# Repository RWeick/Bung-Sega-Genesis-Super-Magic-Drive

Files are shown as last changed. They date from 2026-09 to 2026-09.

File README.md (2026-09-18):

# Bung-Sega-Genesis-Super-Magic-Drive
The bioses and Kicad files for the Bung Super Magic Drive for the Sega Genesis

PCB Thicknesses are documented in the Kicad files.

The motherboard contains two modifications from the original: a bodged resistor pack now has its own footprint and there is a solder jumper to switch between original 16M RAM mode and 32M RAM mode. The 32M RAM mode was a modification that would be done when you sent your system back to Bung for the upgrade. Unfortunately it appears that the upgrade also required the CPLD to be upgraded as well, and a modified CPLD has not yet surfaced to be studied. The upgrade solder jumper and 32M RAM board are therefore provided for a future point where the CPLD is found, studied, and reverse engineered. You may use a 32M RAM card with this system, but it will only register 16M of RAM.

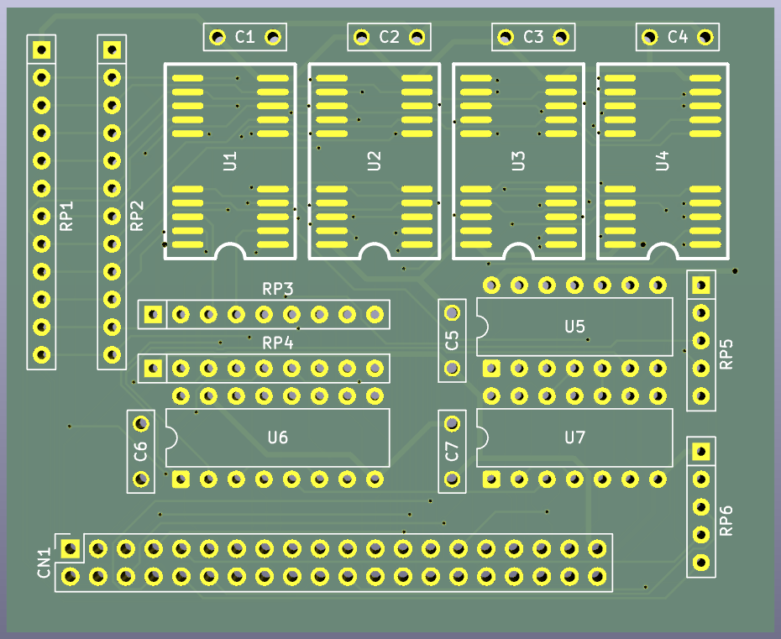
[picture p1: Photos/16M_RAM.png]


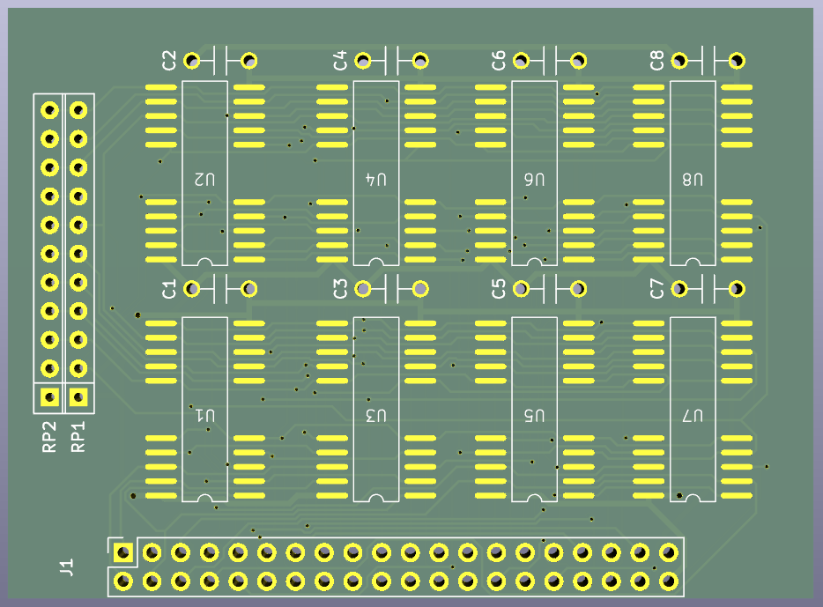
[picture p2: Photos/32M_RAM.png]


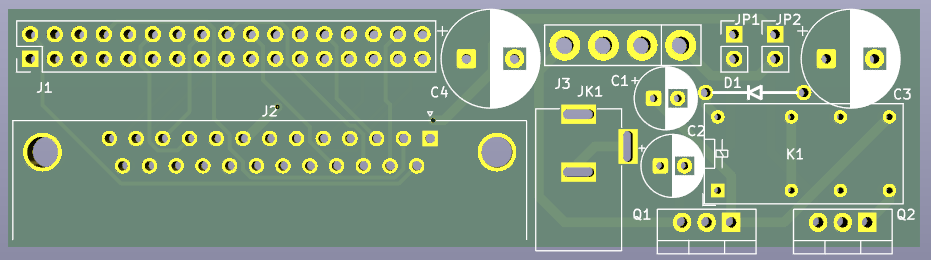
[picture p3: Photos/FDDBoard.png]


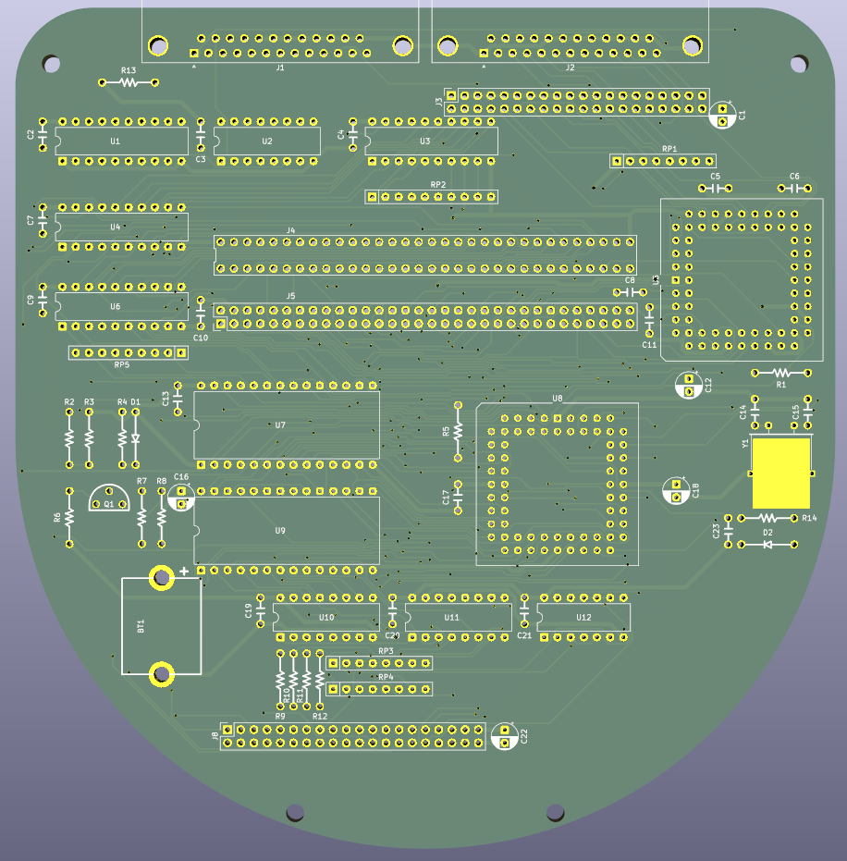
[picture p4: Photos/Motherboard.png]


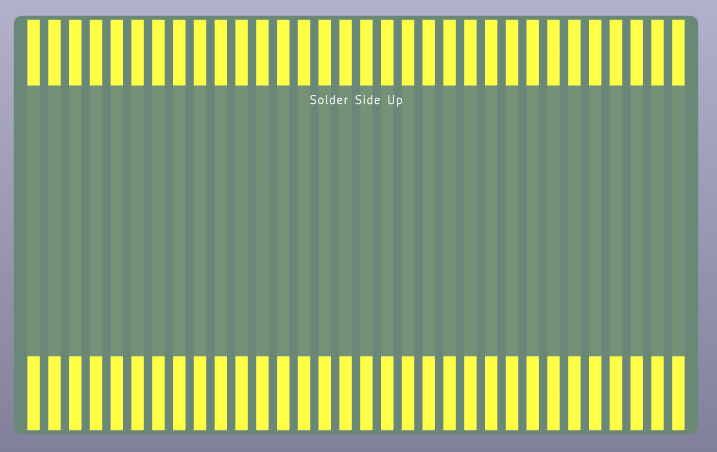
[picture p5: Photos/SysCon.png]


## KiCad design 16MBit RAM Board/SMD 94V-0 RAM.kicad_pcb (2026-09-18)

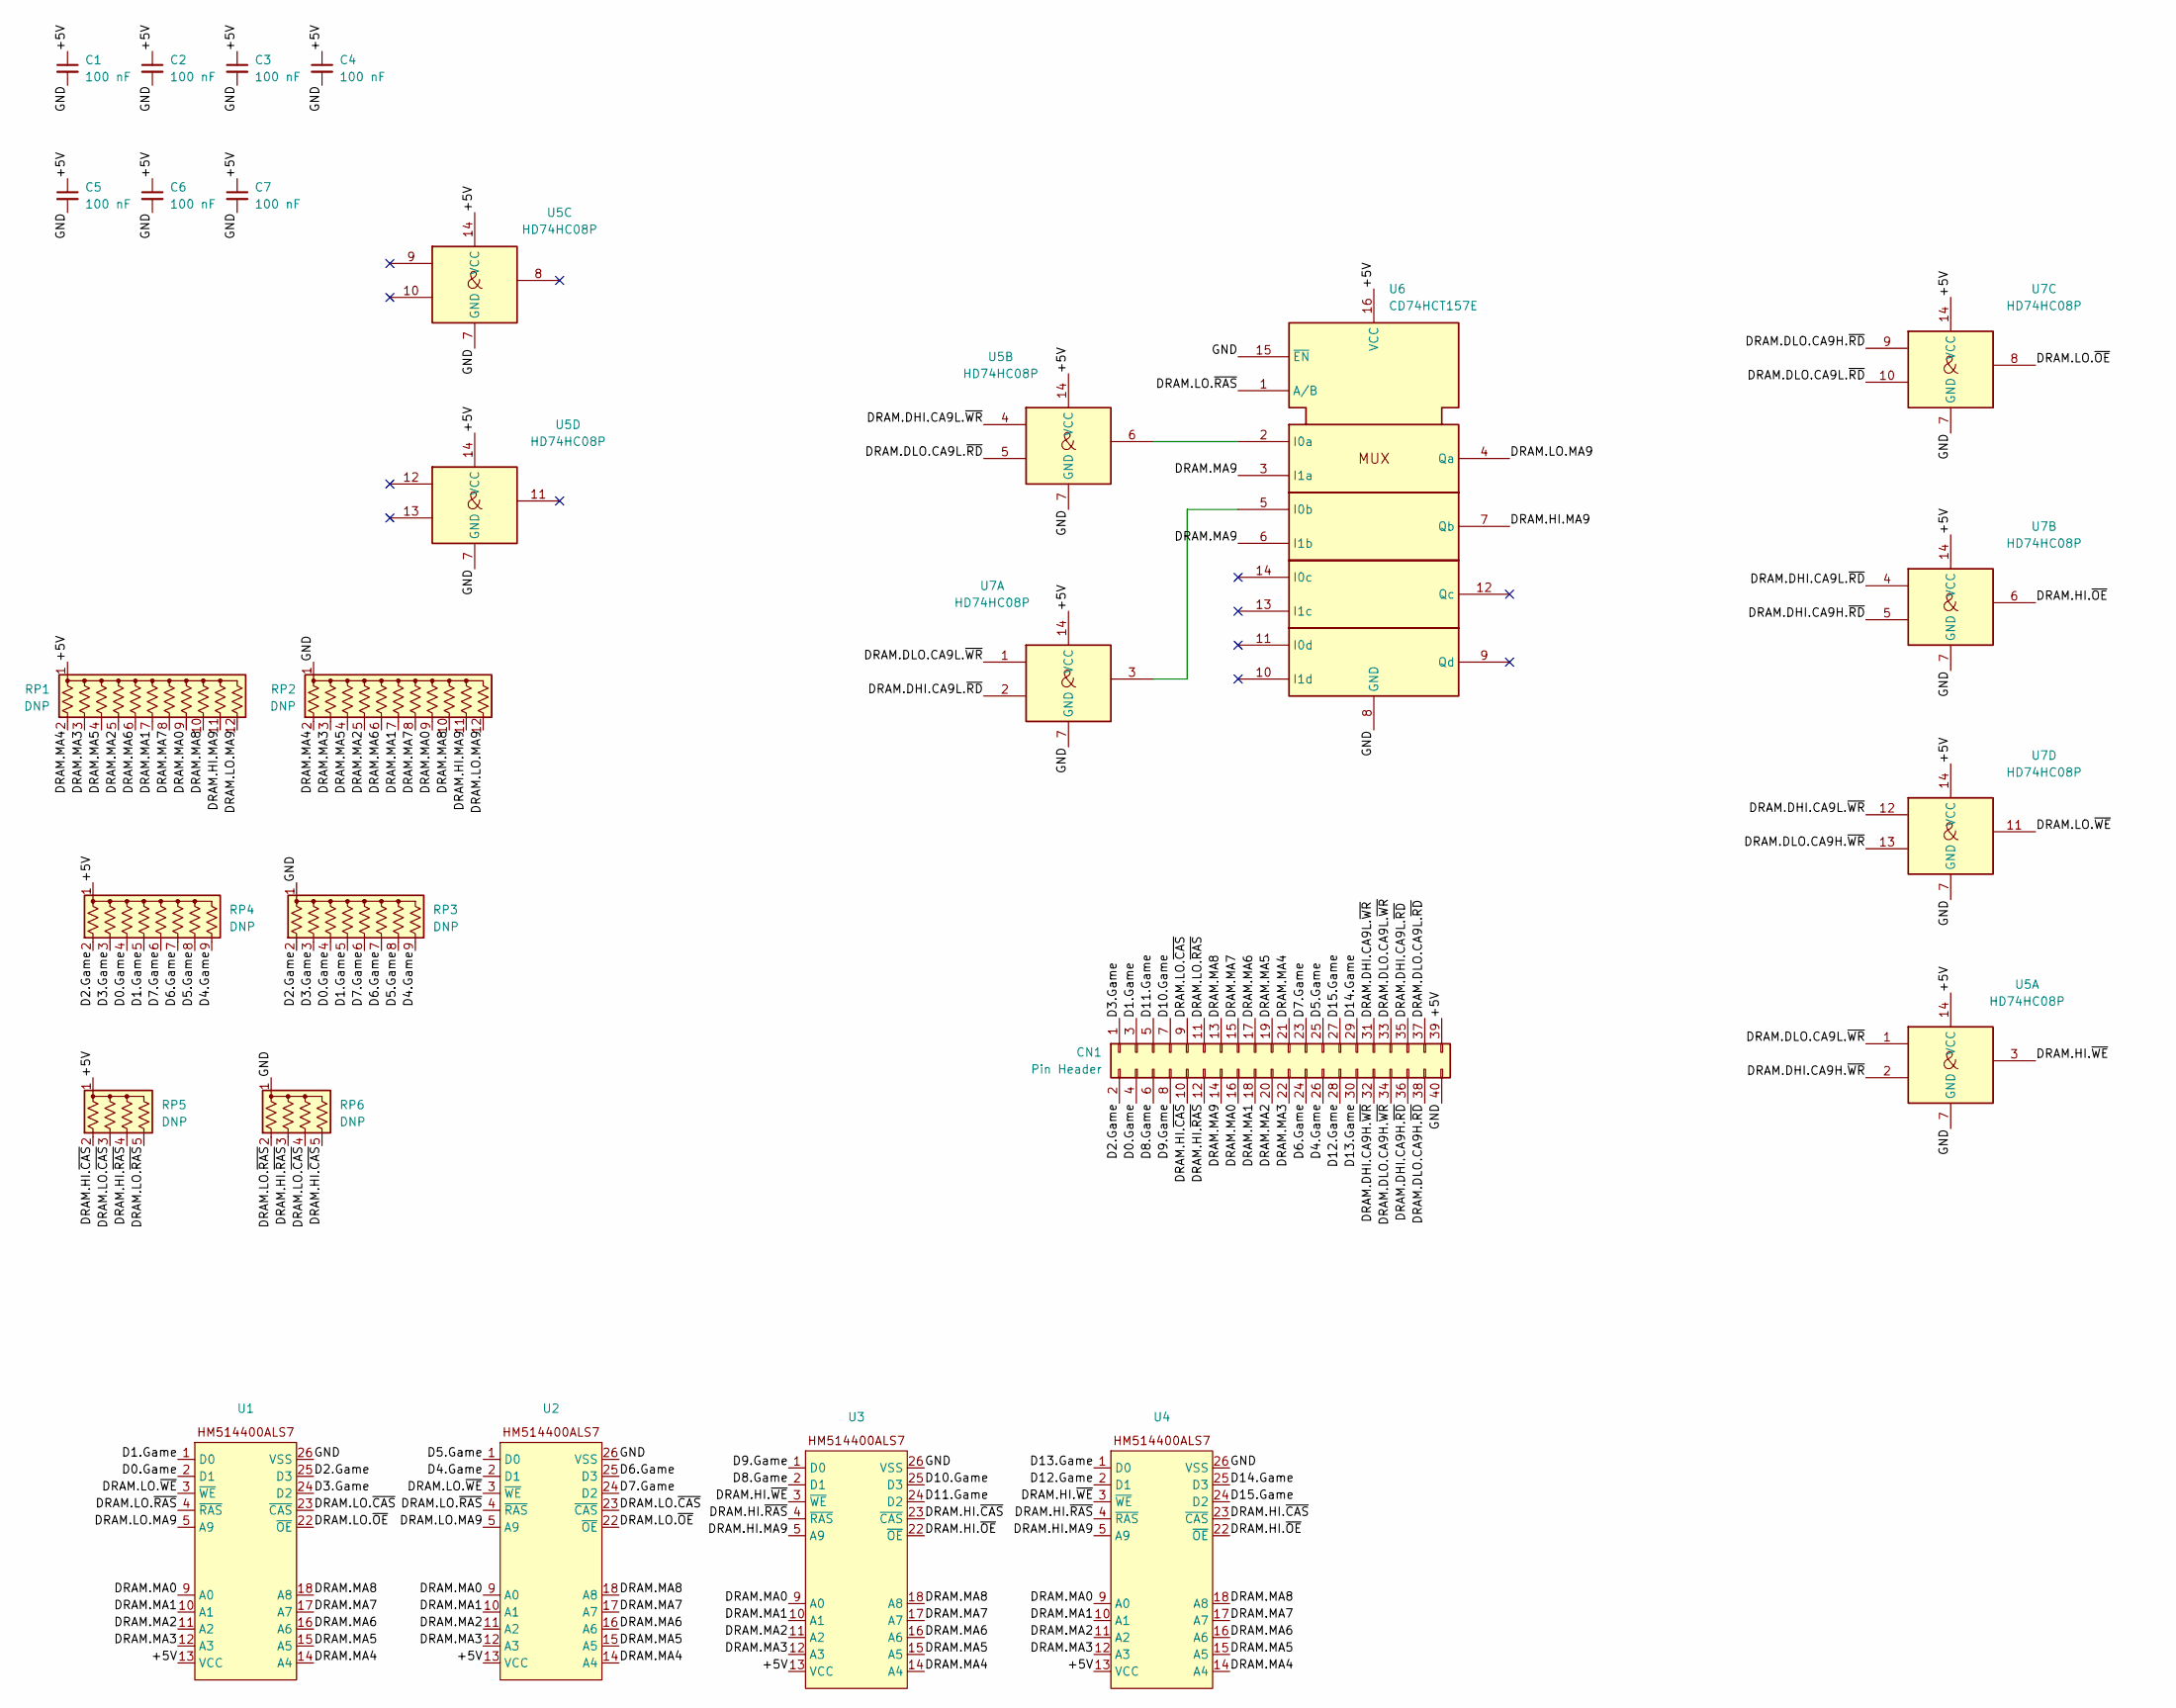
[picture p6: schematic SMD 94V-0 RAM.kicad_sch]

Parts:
C1, C2, C3, C4, C5, C6, C7: 100 nF
CN1: Pin Header
RP1, RP2: DNP; R_Array_SIP12
RP3, RP4: DNP; R_Array_SIP9
RP5, RP6: DNP; R_Array_SIP5
U1, U2, U3, U4: (no value)
U5, U7: HD74HC08P
U6: CD74HCT157E

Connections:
/+5V: C1.1, C2.1, C3.1, C4.1, C5.1, C6.1, C7.1, CN1.39, RP1.1 (common), RP4.1 (common), RP5.1 (common), U1.13 (VCC), U2.13 (VCC), U3.13 (VCC), U4.13 (VCC), U5.14 (VCC), U6.16 (VCC), U7.14 (VCC)
/A0: CN1.16, RP1.9 (R8), RP2.9 (R8), U1.9 (A0), U2.9 (A0), U3.9 (A0), U4.9 (A0)
/A1: CN1.18, RP1.7 (R6), RP2.7 (R6), U1.10 (A1), U2.10 (A1), U3.10 (A1), U4.10 (A1)
/A2: CN1.20, RP1.5 (R4), RP2.5 (R4), U1.11 (A2), U2.11 (A2), U3.11 (A2), U4.11 (A2)
/A3: CN1.22, RP1.3 (R2), RP2.3 (R2), U1.12 (A3), U2.12 (A3), U3.12 (A3), U4.12 (A3)
/A4: CN1.21, RP1.2 (R1), RP2.2 (R1), U1.14 (A4), U2.14 (A4), U3.14 (A4), U4.14 (A4)
/A5: CN1.19, RP1.4 (R3), RP2.4 (R3), U1.15 (A5), U2.15 (A5), U3.15 (A5), U4.15 (A5)
/A6: CN1.17, RP1.6 (R5), RP2.6 (R5), U1.16 (A6), U2.16 (A6), U3.16 (A6), U4.16 (A6)
/A7: CN1.15, RP1.8 (R7), RP2.8 (R7), U1.17 (A7), U2.17 (A7), U3.17 (A7), U4.17 (A7)
/A8: CN1.13, RP1.10 (R9), RP2.10 (R9), U1.18 (A8), U2.18 (A8), U3.18 (A8), U4.18 (A8)
/A9: CN1.14, U6.3 (I1a), U6.6 (I1b)
/GND: C1.2, C2.2, C3.2, C4.2, C5.2, C6.2, C7.2, CN1.40, RP2.1 (common), RP3.1 (common), RP6.1 (common), U1.26 (VSS), U2.26 (VSS), U3.26 (VSS), U4.26 (VSS), U5.7 (GND), U6.8 (GND), U6.15 (~EN), U7.7 (GND)
/RAM1-2.~OE: CN1.38, U7.9
/RAM3-4.~OE: CN1.36, U7.5
/RAM.Bank.1.~OE: CN1.35, U7.2, U7.4
/RAM.Bank.1.~WE: CN1.34, U7.13
/RAM.Bank.2.~OE: CN1.37, U5.5, U7.10
/RAM.Bank.2.~WE: CN1.32, U5.2
/U1-2.A9.~WE.EN: CN1.31, U5.4, U7.12
/U1-U2.A9: RP1.12 (R11), RP2.12 (R11), U1.5 (A9), U2.5 (A9), U6.4 (Qa)
/U1-U2.~CAS: CN1.9, RP5.3 (R2), RP6.4 (R3), U1.23 (~CAS), U2.23 (~CAS)
/U1-U2.~OE: U1.22 (~OE), U2.22 (~OE), U7.8
/U1-U2.~RAS: CN1.11, RP5.5 (R4), RP6.2 (R1), U1.4 (~RAS), U2.4 (~RAS), U6.1 (A/B)
/U1-U2.~WE: U1.3 (~WE), U2.3 (~WE), U7.11
/U1.D0: CN1.3, RP3.5 (R4), RP4.5 (R4), U1.1 (D0)
/U1.D1: CN1.4, RP3.4 (R3), RP4.4 (R3), U1.2 (D1)
/U1.D2: CN1.1, RP3.3 (R2), RP4.3 (R2), U1.24 (D2)
/U1.D3: CN1.2, RP3.2 (R1), RP4.2 (R1), U1.25 (D3)
/U2.D0: CN1.25, RP3.8 (R7), RP4.8 (R7), U2.1 (D0)
/U2.D1: CN1.26, RP3.9 (R8), RP4.9 (R8), U2.2 (D1)
/U2.D2: CN1.23, RP3.6 (R5), RP4.6 (R5), U2.24 (D2)
/U2.D3: CN1.24, RP3.7 (R6), RP4.7 (R6), U2.25 (D3)
/U3-4.A9.~WE.EN: CN1.33, U5.1, U7.1
/U3-U4.A9: RP1.11 (R10), RP2.11 (R10), U3.5 (A9), U4.5 (A9), U6.7 (Qb)
/U3-U4.~CAS: CN1.10, RP5.2 (R1), RP6.5 (R4), U3.23 (~CAS), U4.23 (~CAS)
/U3-U4.~OE: U3.22 (~OE), U4.22 (~OE), U7.6
/U3-U4.~RAS: CN1.12, RP5.4 (R3), RP6.3 (R2), U3.4 (~RAS), U4.4 (~RAS)
/U3-U4.~WE: U3.3 (~WE), U4.3 (~WE), U5.3
/U3.D0: CN1.8, U3.1 (D0)
/U3.D1: CN1.6, U3.2 (D1)
/U3.D2: CN1.5, U3.24 (D2)
/U3.D3: CN1.7, U3.25 (D3)
/U4.D0: CN1.30, U4.1 (D0)
/U4.D1: CN1.28, U4.2 (D1)
/U4.D2: CN1.27, U4.24 (D2)
/U4.D3: CN1.29, U4.25 (D3)
unnamed: U5.6, U6.2 (I0a)
unnamed: U6.5 (I0b), U7.3

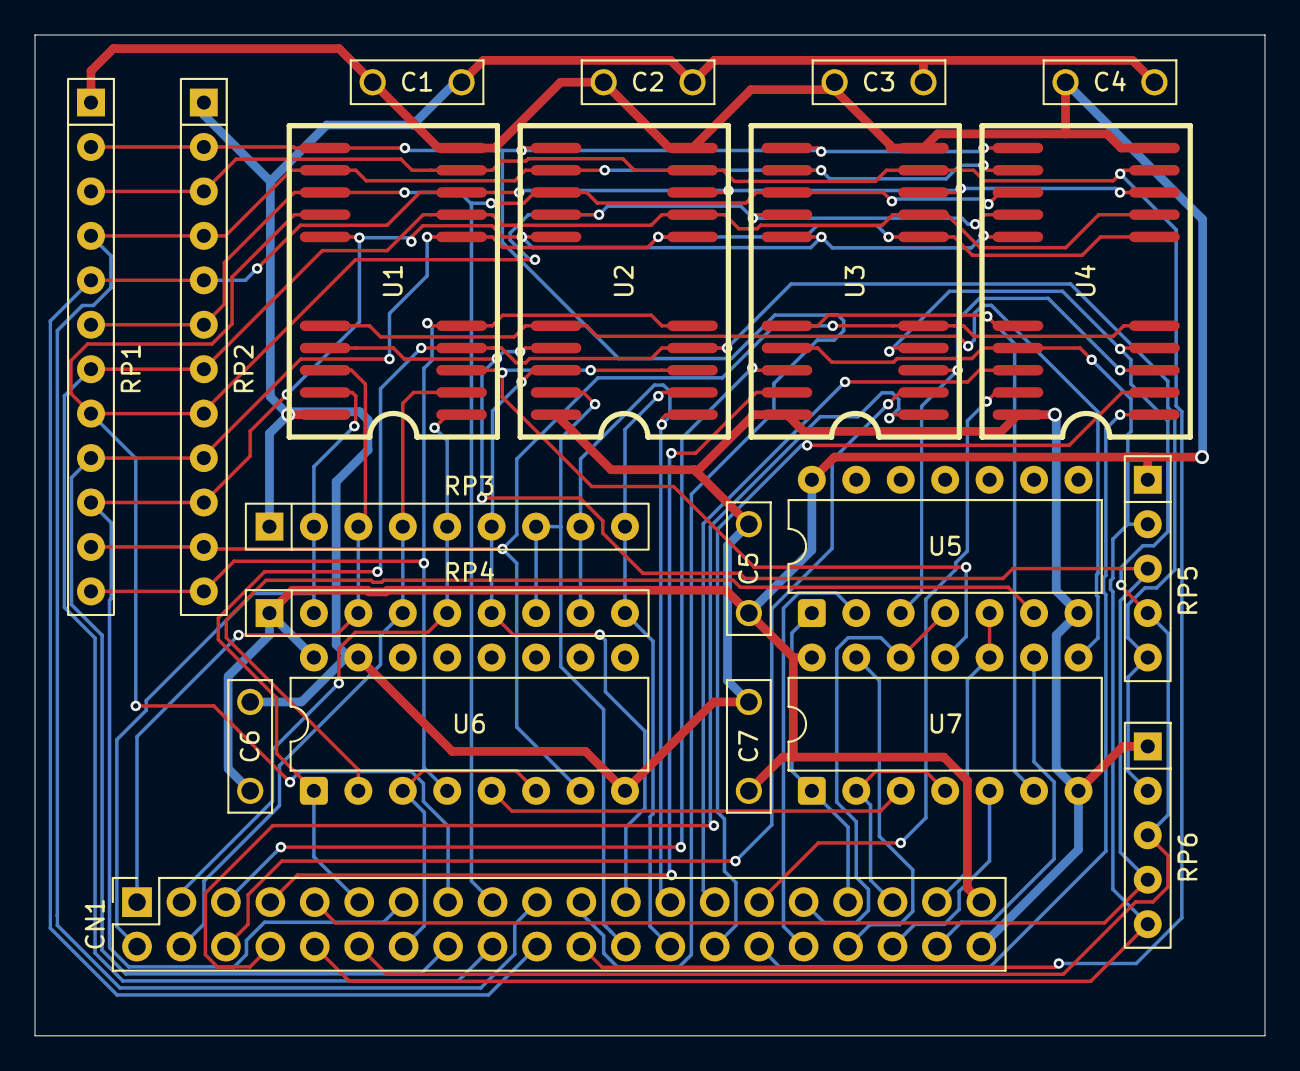
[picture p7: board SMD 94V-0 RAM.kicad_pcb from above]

Board: 2 copper layers, 70.3 x 57.2 mm, 21 parts (0 on the bottom side), 48 nets.

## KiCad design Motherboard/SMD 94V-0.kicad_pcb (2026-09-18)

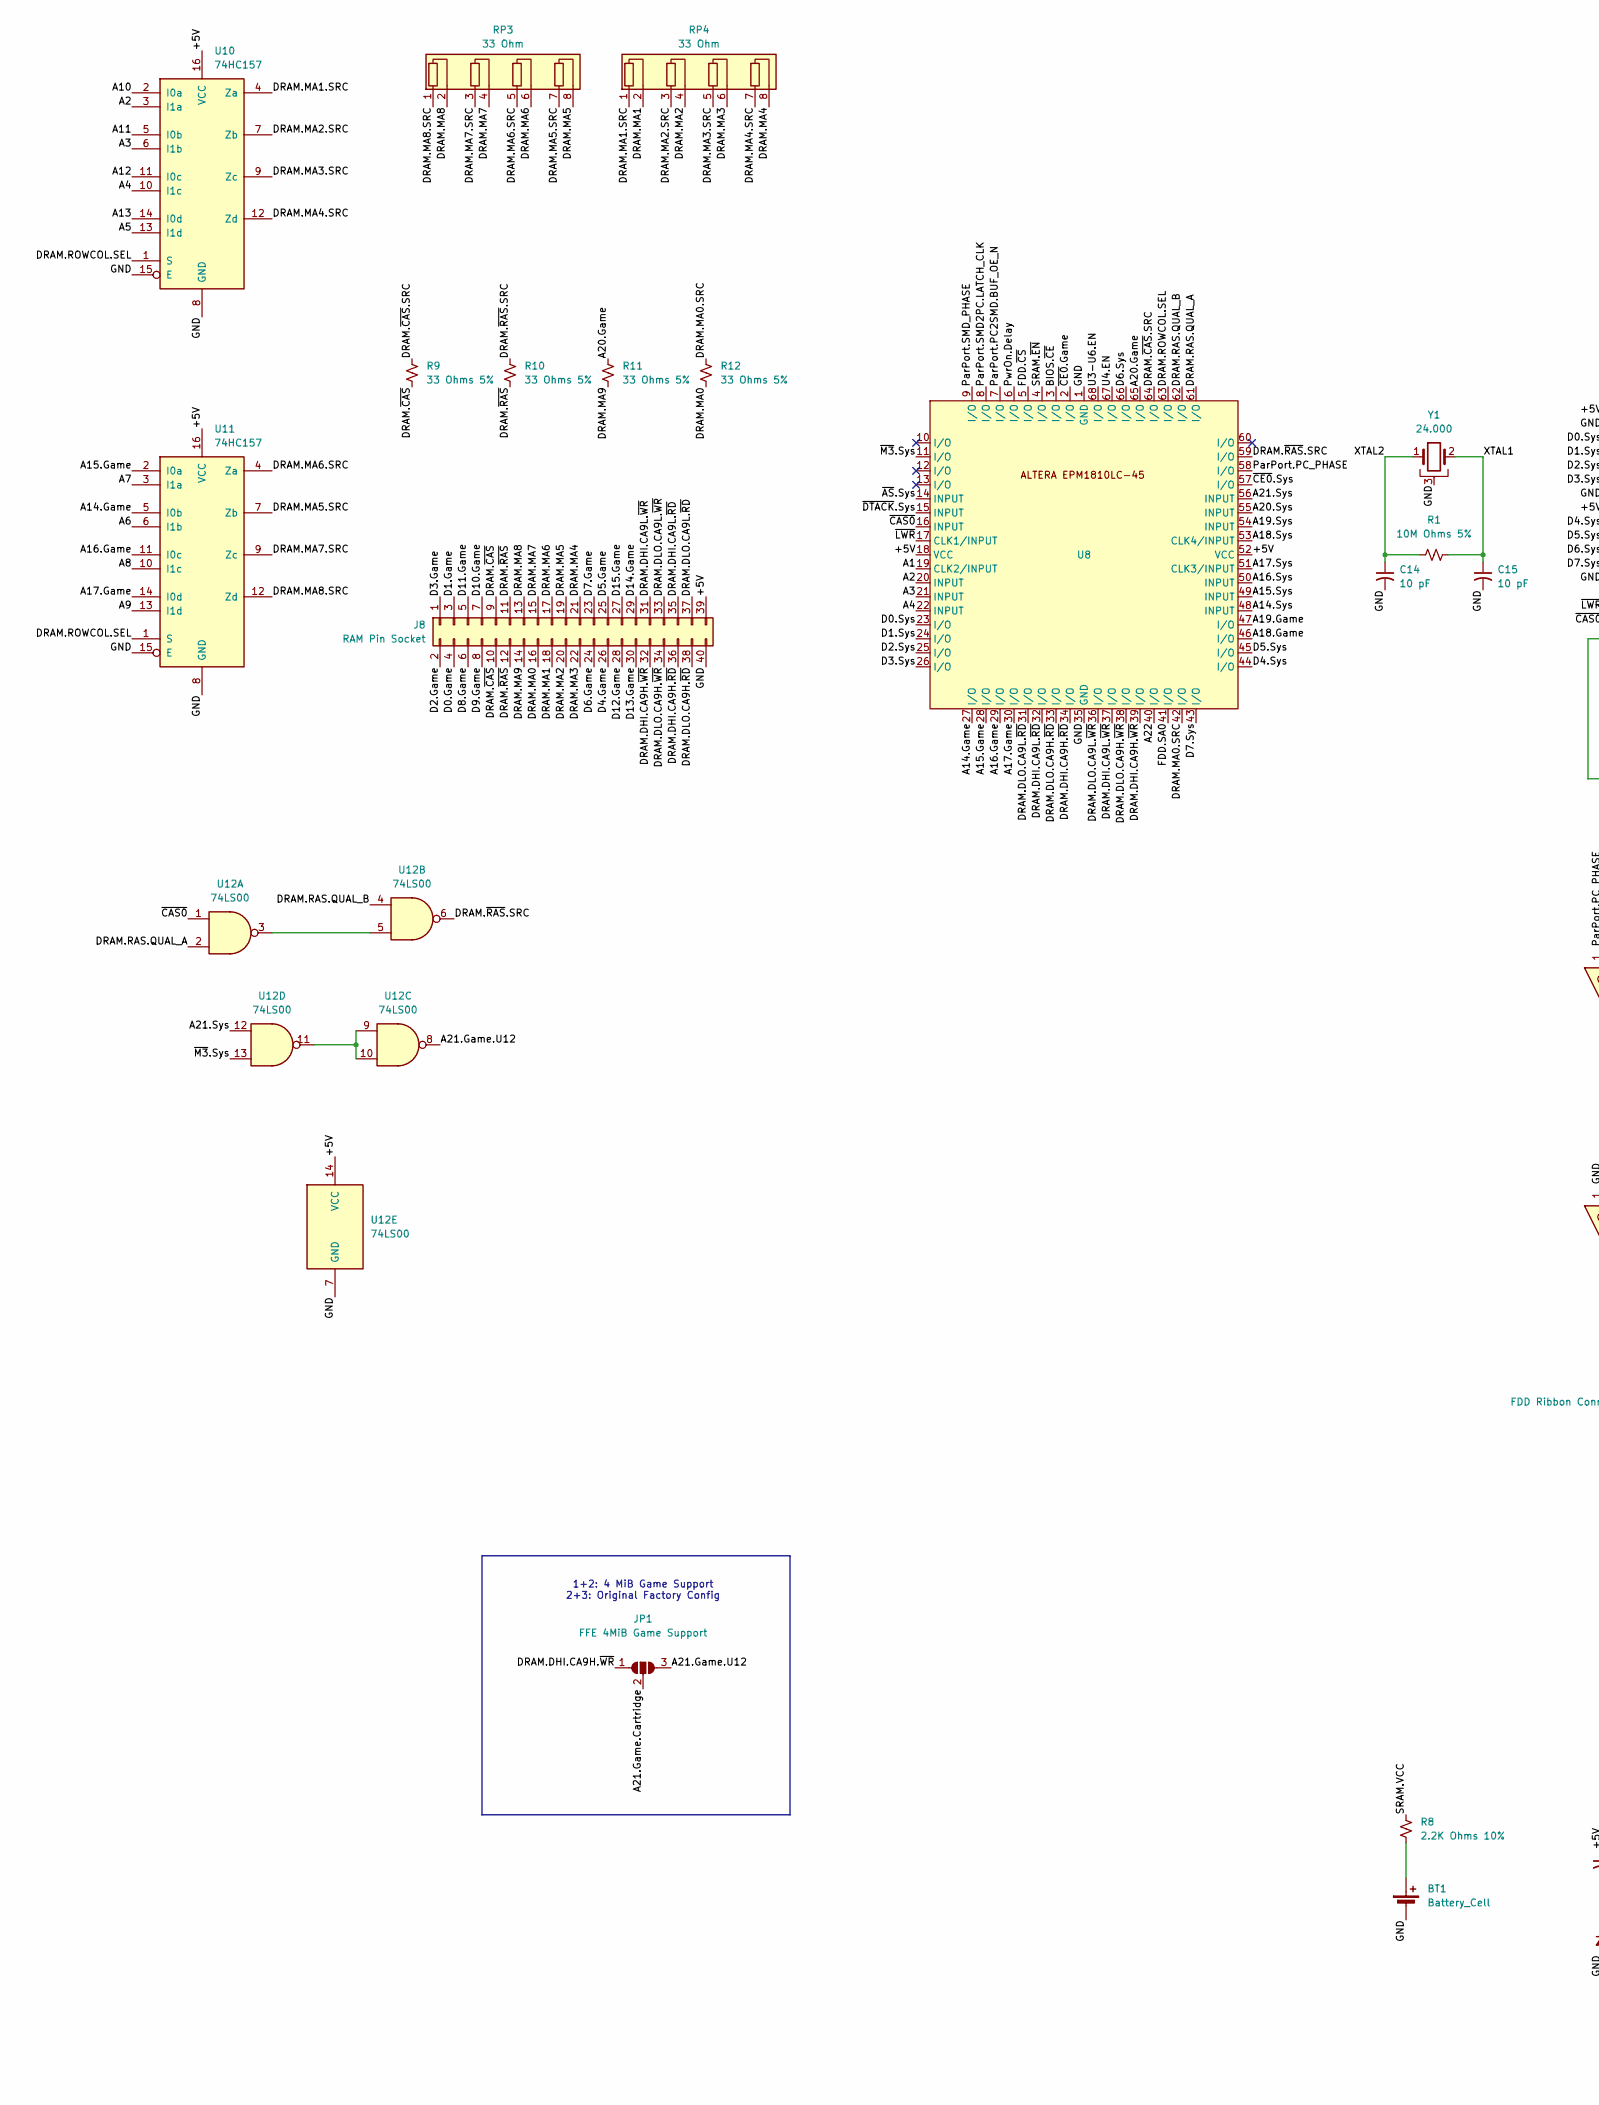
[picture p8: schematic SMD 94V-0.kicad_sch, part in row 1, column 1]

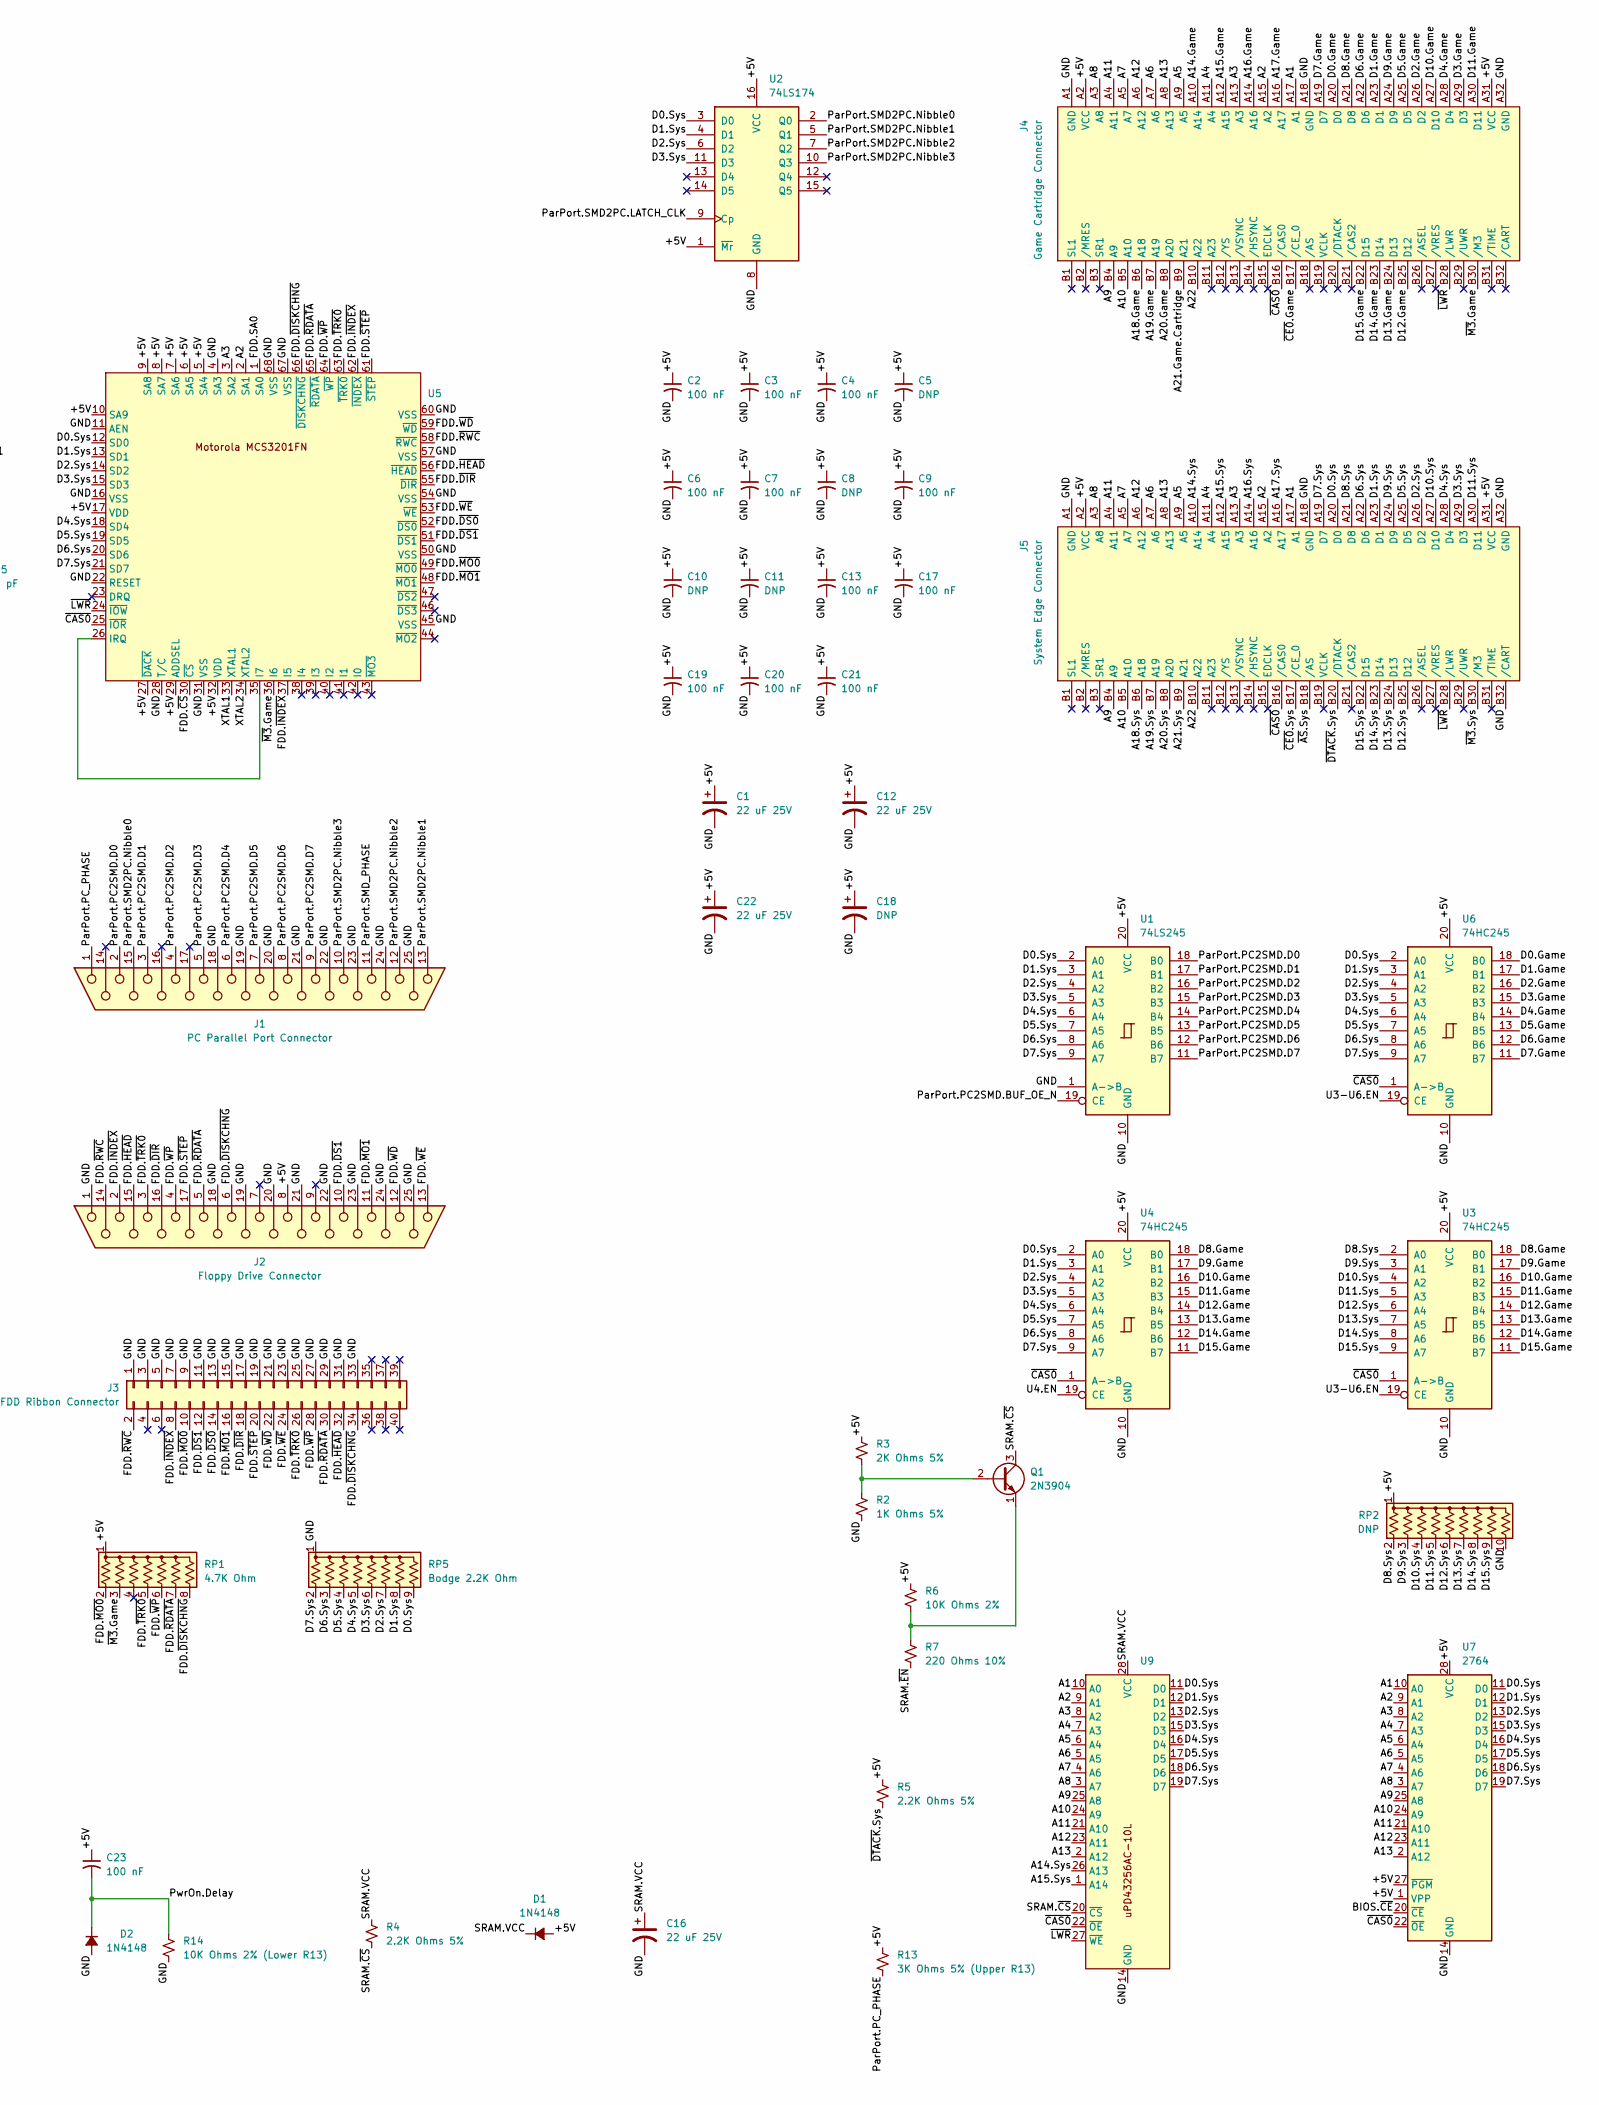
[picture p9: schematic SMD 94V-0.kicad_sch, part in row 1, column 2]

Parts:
BT1: Battery_Cell; Battery
C1, C12, C16, C22: 22 uF 25V; CP_Radial_D5.0mm_P2.50mm
C2, C3, C4, C6, C7, C9, C13, C17, C19, C20, C21, C23: 100 nF; Capacitor
C5, C8, C10, C11: DNP; Capacitor
C14, C15: 10 pF; Capacitor
C18: DNP; CP_Radial_D5.0mm_P2.50mm
D1, D2: 1N4148; Diode
J1: PC Parallel Port Connector; DSUB-25_Socket_Horizontal_P2.77x2.84mm_EdgePinOffset7.70mm_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
J2: Floppy Drive Connector; DSUB-25_Socket_Horizontal_P2.77x2.84mm_EdgePinOffset7.70mm_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
J3: FDD Ribbon Connector; PinHeader_2x20_P2.54mm_Vertical
J4: Game Cartridge Connector; Cartridge Slot
J5: System Edge Connector; PinHeader_2x32_P2.54mm_Vertical
J8: RAM Pin Socket; PinHeader_2x20_P2.54mm_Vertical
JP1: FFE 4MiB Game Support; SolderJumper-3_P1.3mm_Open_RoundedPad1.0x1.5mm_NumberLabels
Q1: 2N3904; Transistor
R1: 10M Ohms 5%; Resistor
R2: 1K Ohms 5%; Resistor
R3: 2K Ohms 5%; Resistor
R4, R5: 2.2K Ohms 5%; Resistor
R6: 10K Ohms 2%; Resistor
R7: 220 Ohms 10%; Resistor
R8: 2.2K Ohms 10%; Resistor
R9, R10, R11, R12: 33 Ohms 5%; Resistor
R13: 3K Ohms 5% (Upper R13); Resistor
R14: 10K Ohms 2% (Lower R13); Resistor
RP1: 4.7K Ohm; R_Array_SIP8
RP2: DNP; R_Array_SIP10
RP3, RP4: 33 Ohm; R_Array_SIP8
RP5: Bodge 2.2K Ohm; R_Array_SIP9
U1: 74LS245; DIP-20_W7.62mm
U2: 74LS174; DIP-16_W7.62mm
U3, U4, U6: 74HC245; DIP-20_W7.62mm
U5, U8: PLCC-68_THT-Socket
U7: 2764; DIP-28_W15.24mm
U9: DIP-28_W15.24mm
U10, U11: 74HC157; DIP-16_W7.62mm
U12: 74LS00; DIP-14_W7.62mm
Y1: 24.000; Crystal_HC18-U_Horizontal_1EP_style2

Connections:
/+5V: C1.1, C2.1, C3.1, C4.1, C5.1, C6.1, C7.1, C8.1, C9.1, C10.1, C11.1, C12.1, C13.1, C17.1, C18.1, C19.1, C20.1, C21.1, C22.1, C23.1, D1.2 (A), J2.8, J4.A2 (VCC), J4.A31 (VCC), J5.A2 (VCC), J5.A31 (VCC), J8.39, R3.1, R5.1, R6.1, R13.1, RP1.1 (common), RP2.1 (common), U1.20 (VCC), U2.1 (~Mr), U2.16 (VCC), U3.20 (VCC), U4.20 (VCC), U5.5 (SA4), U5.6 (SA5), U5.7 (SA6), U5.8 (SA7), U5.9 (SA8), U5.10 (SA9), U5.17 (VDD), U5.27 (~DACK), U5.29 (ADDSEL), U5.32 (VDD), U6.20 (VCC), U7.1 (VPP), U7.27 (~PGM), U7.28 (VCC), U8.18 (VCC), U8.52 (VCC), U10.16 (VCC), U11.16 (VCC), U12.14 (VCC)
/A1: J4.A17 (A1), J5.A17 (A1), U7.10 (A0), U8.19 (CLK2/INPUT), U9.10 (A0)
/A2: J4.A15 (A2), J5.A15 (A2), U5.2 (SA1), U7.9 (A1), U8.20 (INPUT), U9.9 (A1), U10.3 (I1a)
/A3: J4.A13 (A3), J5.A13 (A3), U5.3 (SA2), U7.8 (A2), U8.21 (INPUT), U9.8 (A2), U10.6 (I1b)
/A4: J4.A11 (A4), J5.A11 (A4), U7.7 (A3), U8.22 (INPUT), U9.7 (A3), U10.10 (I1c)
/A5: J4.A9 (A5), J5.A9 (A5), U7.6 (A4), U9.6 (A4), U10.13 (I1d)
/A6: J4.A7 (A6), J5.A7 (A6), U7.5 (A5), U9.5 (A5), U11.6 (I1b)
/A7: J4.A5 (A7), J5.A5 (A7), U7.4 (A6), U9.4 (A6), U11.3 (I1a)
/A8: J4.A3 (A8), J5.A3 (A8), U7.3 (A7), U9.3 (A7), U11.10 (I1c)
/A9: J4.B4 (A9), J5.B4 (A9), U7.25 (A8), U9.25 (A8), U11.13 (I1d)
/A10: J4.B5 (A10), J5.B5 (A10), U7.24 (A9), U9.24 (A9), U10.2 (I0a)
/A11: J4.A4 (A11), J5.A4 (A11), U7.21 (A10), U9.21 (A10), U10.5 (I0b)
/A12: J4.A6 (A12), J5.A6 (A12), U7.23 (A11), U9.23 (A11), U10.11 (I0c)
/A13: J4.A8 (A13), J5.A8 (A13), U7.2 (A12), U9.2 (A12), U10.14 (I0d)
/A14.Game: J4.A10 (A14), U8.27 (I/O), U11.5 (I0b)
/A14.Sys: J5.A10 (A14), U8.48 (INPUT), U9.26 (A13)
/A15.Game: J4.A12 (A15), U8.28 (I/O), U11.2 (I0a)
/A15.Sys: J5.A12 (A15), U8.49 (INPUT), U9.1 (A14)
/A16.Game: J4.A14 (A16), U8.29 (I/O), U11.11 (I0c)
/A16.Sys: J5.A14 (A16), U8.50 (INPUT)
/A17.Game: J4.A16 (A17), U8.30 (I/O), U11.14 (I0d)
/A17.Sys: J5.A16 (A17), U8.51 (CLK3/INPUT)
/A18.Game: J4.B6 (A18), U8.46 (I/O)
/A18.Sys: J5.B6 (A18), U8.53 (CLK4/INPUT)
/A19.Game: J4.B7 (A19), U8.47 (I/O)
/A19.Sys: J5.B7 (A19), U8.54 (INPUT)
/A20.Game: J4.B8 (A20), R11.1, U8.65 (I/O)
/A20.Sys: J5.B8 (A20), U8.55 (INPUT)
/A21.Game.Cartridge: J4.B9 (A21), JP1.2 (C)
/A21.Game.U12: JP1.3 (B), U12.8
/A21.Sys: J5.B9 (A21), U8.56 (INPUT), U12.12
/A22: J4.B10 (A22), J5.B10 (A22), U8.40 (I/O)
/BIOS.~CE: U7.20 (~CE), U8.3 (I/O)
/D0.Game: J4.A20 (D0), J8.4, U6.18 (B0)
/D0.Sys: J5.A20 (D0), RP5.9 (R8), U1.2 (A0), U2.3 (D0), U4.2 (A0), U5.12 (SD0), U6.2 (A0), U7.11 (D0), U8.23 (I/O), U9.11 (D0)
/D1.Game: J4.A23 (D1), J8.3, U6.17 (B1)
/D1.Sys: J5.A23 (D1), RP5.8 (R7), U1.3 (A1), U2.4 (D1), U4.3 (A1), U5.13 (SD1), U6.3 (A1), U7.12 (D1), U8.24 (I/O), U9.12 (D1)
/D2.Game: J4.A26 (D2), J8.2, U6.16 (B2)
/D2.Sys: J5.A26 (D2), RP5.7 (R6), U1.4 (A2), U2.6 (D2), U4.4 (A2), U5.14 (SD2), U6.4 (A2), U7.13 (D2), U8.25 (I/O), U9.13 (D2)
/D3.Game: J4.A29 (D3), J8.1, U6.15 (B3)
/D3.Sys: J5.A29 (D3), RP5.6 (R5), U1.5 (A3), U2.11 (D3), U4.5 (A3), U5.15 (SD3), U6.5 (A3), U7.15 (D3), U8.26 (I/O), U9.15 (D3)
/D4.Game: J4.A28 (D4), J8.26, U6.14 (B4)
/D4.Sys: J5.A28 (D4), RP5.5 (R4), U1.6 (A4), U4.6 (A4), U5.18 (SD4), U6.6 (A4), U7.16 (D4), U8.44 (I/O), U9.16 (D4)
/D5.Game: J4.A25 (D5), J8.25, U6.13 (B5)
/D5.Sys: J5.A25 (D5), RP5.4 (R3), U1.7 (A5), U4.7 (A5), U5.19 (SD5), U6.7 (A5), U7.17 (D5), U8.45 (I/O), U9.17 (D5)
/D6.Game: J4.A22 (D6), J8.24, U6.12 (B6)
/D6.Sys: J5.A22 (D6), RP5.3 (R2), U1.8 (A6), U4.8 (A6), U5.20 (SD6), U6.8 (A6), U7.18 (D6), U8.66 (I/O), U9.18 (D6)
/D7.Game: J4.A19 (D7), J8.23, U6.11 (B7)
/D7.Sys: J5.A19 (D7), RP5.2 (R1), U1.9 (A7), U4.9 (A7), U5.21 (SD7), U6.9 (A7), U7.19 (D7), U8.43 (I/O), U9.19 (D7)
/D8.Game: J4.A21 (D8), J8.6, U3.18 (B0), U4.18 (B0)
/D8.Sys: J5.A21 (D8), RP2.2 (R1), U3.2 (A0)
/D9.Game: J4.A24 (D9), J8.8, U3.17 (B1), U4.17 (B1)
/D9.Sys: J5.A24 (D9), RP2.3 (R2), U3.3 (A1)
/D10.Game: J4.A27 (D10), J8.7, U3.16 (B2), U4.16 (B2)
/D10.Sys: J5.A27 (D10), RP2.4 (R3), U3.4 (A2)
/D11.Game: J4.A30 (D11), J8.5, U3.15 (B3), U4.15 (B3)
/D11.Sys: J5.A30 (D11), RP2.5 (R4), U3.5 (A3)
/D12.Game: J4.B25 (D12), J8.28, U3.14 (B4), U4.14 (B4)
/D12.Sys: J5.B25 (D12), RP2.6 (R5), U3.6 (A4)
/D13.Game: J4.B24 (D13), J8.30, U3.13 (B5), U4.13 (B5)
/D13.Sys: J5.B24 (D13), RP2.7 (R6), U3.7 (A5)
/D14.Game: J4.B23 (D14), J8.29, U3.12 (B6), U4.12 (B6)
/D14.Sys: J5.B23 (D14), RP2.8 (R7), U3.8 (A6)
/D15.Game: J4.B22 (D15), J8.27, U3.11 (B7), U4.11 (B7)
/D15.Sys: J5.B22 (D15), RP2.9 (R8), U3.9 (A7)
/DRAM.DHI.CA9H.~RD: J8.36, U8.34 (I/O)
/DRAM.DHI.CA9H.~WR: J8.32, JP1.1 (A), U8.39 (I/O)
/DRAM.DHI.CA9L.~RD: J8.35, U8.32 (I/O)
/DRAM.DHI.CA9L.~WR: J8.31, U8.37 (I/O)
/DRAM.DLO.CA9H.~RD: J8.38, U8.33 (I/O)
/DRAM.DLO.CA9H.~WR: J8.34, U8.38 (I/O)
/DRAM.DLO.CA9L.~RD: J8.37, U8.31 (I/O)
/DRAM.DLO.CA9L.~WR: J8.33, U8.36 (I/O)
/DRAM.MA0: J8.16, R12.2
/DRAM.MA0.SRC: R12.1, U8.42 (I/O)
/DRAM.MA1: J8.18, RP4.2 (R1.2)
/DRAM.MA1.SRC: RP4.1 (R1.1), U10.4 (Za)
/DRAM.MA2: J8.20, RP4.4 (R2.2)
/DRAM.MA2.SRC: RP4.3 (R2.1), U10.7 (Zb)
/DRAM.MA3: J8.22, RP4.6 (R3.2)
/DRAM.MA3.SRC: RP4.5 (R3.1), U10.9 (Zc)
/DRAM.MA4: J8.21, RP4.8 (R4.2)
/DRAM.MA4.SRC: RP4.7 (R4.1), U10.12 (Zd)
/DRAM.MA5: J8.19, RP3.8 (R4.2)
/DRAM.MA5.SRC: RP3.7 (R4.1), U11.7 (Zb)
/DRAM.MA6: J8.17, RP3.6 (R3.2)
/DRAM.MA6.SRC: RP3.5 (R3.1), U11.4 (Za)
/DRAM.MA7: J8.15, RP3.4 (R2.2)
/DRAM.MA7.SRC: RP3.3 (R2.1), U11.9 (Zc)
/DRAM.MA8: J8.13, RP3.2 (R1.2)
/DRAM.MA8.SRC: RP3.1 (R1.1), U11.12 (Zd)
/DRAM.MA9: J8.14, R11.2
/DRAM.RAS.QUAL_A: U8.61 (I/O), U12.2
/DRAM.RAS.QUAL_B: U8.62 (I/O), U12.4
/DRAM.ROWCOL.SEL: U8.63 (I/O), U10.1 (S), U11.1 (S)
/DRAM.~CAS: J8.9, J8.10, R9.2
/DRAM.~CAS.SRC: R9.1, U8.64 (I/O)
/DRAM.~RAS: J8.11, J8.12, R10.2
/DRAM.~RAS.SRC: R10.1, U8.59 (I/O), U12.6
/FDD.SA0: U5.1 (SA0), U8.41 (I/O)
/FDD.~CS: U5.30 (~CS), U8.5 (I/O)
/FDD.~DIR: J2.16, J3.18, U5.55 (~DIR)
/FDD.~DISKCHNG: J2.6, J3.34, RP1.8 (R7), U5.66 (~DISKCHNG)
/FDD.~DS0: J3.14, U5.52 (~DS0)
/FDD.~DS1: J2.10, J3.12, U5.51 (~DS1)
/FDD.~HEAD: J2.15, J3.32, U5.56 (~HEAD)
/FDD.~INDEX: J2.2, J3.8, U5.37 (I5), U5.62 (~INDEX)
/FDD.~MO0: J3.10, RP1.2 (R1), U5.49 (~MO0)
/FDD.~MO1: J2.11, J3.16, U5.48 (~MO1)
/FDD.~RDATA: J2.5, J3.30, RP1.7 (R6), U5.65 (~RDATA)
/FDD.~RWC: J2.14, J3.2, U5.58 (~RWC)
/FDD.~STEP: J2.17, J3.20, U5.61 (~STEP)
/FDD.~TRK0: J2.3, J3.26, RP1.5 (R4), U5.63 (~TRK0)
/FDD.~WD: J2.12, J3.22, U5.59 (~WD)
/FDD.~WE: J2.13, J3.24, U5.53 (~WE)
/FDD.~WP: J2.4, J3.28, RP1.6 (R5), U5.64 (~WP)
/GND: BT1.2 (-), C1.2, C2.2, C3.2, C4.2, C5.2, C6.2, C7.2, C8.2, C9.2, C10.2, C11.2, C12.2, C13.2, C14.2, C15.2, C16.2, C17.2, C18.2, C19.2, C20.2, C21.2, C22.2, D2.2 (A), J1.18, J1.19, J1.20, J1.21, J1.22, J1.23, J1.24, J1.25, J1.SH, J2.1, J2.18, J2.19, J2.20, J2.21, J2.22, J2.23, J2.24, J2.25, J2.SH, J3.1, J3.3, J3.5, J3.7, J3.9, J3.11, J3.13, J3.15, J3.17, J3.19, J3.21, J3.23, J3.25, J3.27, J3.29, J3.31, J3.33, J4.A1 (GND), J4.A18 (GND), J4.A32 (GND), J5.A1 (GND), J5.A18 (GND), J5.A32 (GND), J5.B32 (/CART), J8.40, R2.2, R14.2, RP2.10 (R9), RP5.1 (common), U1.1 (A->B), U1.10 (GND), U2.8 (GND), U3.10 (GND), U4.10 (GND), U5.4 (SA3), U5.11 (AEN), U5.16 (VSS), U5.22 (RESET), U5.28 (T/C), U5.31 (VSS), U5.45 (VSS), U5.50 (VSS), U5.54 (VSS), U5.57 (VSS), U5.60 (VSS), U5.67 (VSS), U5.68 (VSS), U6.10 (GND), U7.14 (GND), U8.1 (GND), U8.35 (GND), U9.14 (GND), U10.8 (GND), U10.15 (E), U11.8 (GND), U11.15 (E), U12.7 (GND), Y1.3
/ParPort.PC2SMD.BUF_OE_N: U1.19 (CE), U8.7 (I/O)
/ParPort.PC2SMD.D0: J1.2, U1.18 (B0)
/ParPort.PC2SMD.D1: J1.3, U1.17 (B1)
/ParPort.PC2SMD.D2: J1.4, U1.16 (B2)
/ParPort.PC2SMD.D3: J1.5, U1.15 (B3)
/ParPort.PC2SMD.D4: J1.6, U1.14 (B4)
/ParPort.PC2SMD.D5: J1.7, U1.13 (B5)
/ParPort.PC2SMD.D6: J1.8, U1.12 (B6)
/ParPort.PC2SMD.D7: J1.9, U1.11 (B7)
/ParPort.PC_PHASE: J1.1, R13.2, U8.58 (I/O)
/ParPort.SMD2PC.LATCH_CLK: U2.9 (Cp), U8.8 (I/O)
/ParPort.SMD2PC.Nibble0: J1.15, U2.2 (Q0)
/ParPort.SMD2PC.Nibble1: J1.13, U2.5 (Q1)
/ParPort.SMD2PC.Nibble2: J1.12, U2.7 (Q2)
/ParPort.SMD2PC.Nibble3: J1.10, U2.10 (Q3)
/ParPort.SMD_PHASE: J1.11, U8.9 (I/O)
/PwrOn.Delay: C23.2, D2.1 (K), R14.1, U8.6 (I/O)
/SRAM.VCC: C16.1, D1.1 (K), R4.1, R8.1, U9.28 (VCC)
/SRAM.~CS: Q1.3 (C), R4.2, U9.20 (~CS)
/SRAM.~EN: R7.2, U8.4 (I/O)
/U3-U6.EN: U3.19 (CE), U6.19 (CE), U8.68 (I/O)
/U4.EN: U4.19 (CE), U8.67 (I/O)
/XTAL1: C15.1, R1.2, U5.33 (XTAL1), Y1.2
/XTAL2: C14.1, R1.1, U5.34 (XTAL2), Y1.1
/~AS.Sys: J5.B18 (/AS), U8.14 (INPUT)
/~CAS0: J4.B16 (/CAS0), J5.B16 (/CAS0), U3.1 (A->B), U4.1 (A->B), U5.25 (~IOR), U6.1 (A->B), U7.22 (~OE), U8.16 (INPUT), U9.22 (~OE), U12.1
/~CE0.Game: J4.B17 (/CE_0), U8.2 (I/O)
/~CE0.Sys: J5.B17 (/CE_0), U8.57 (I/O)
/~DTACK.Sys: J5.B20 (/DTACK), R5.2, U8.15 (INPUT)
/~LWR: J4.B28 (/LWR), J5.B28 (/LWR), U5.24 (~IOW), U8.17 (CLK1/INPUT), U9.27 (~WE)
/~M3.Game: J4.B30 (/M3), RP1.3 (R2), U5.36 (I6)
/~M3.Sys: J5.B30 (/M3), U8.11 (I/O), U12.13
unnamed: BT1.1 (+), R8.2
unnamed: Q1.2 (B), R2.1, R3.2
unnamed: Q1.1 (E), R6.2, R7.1
unnamed: U5.26 (IRQ), U5.35 (I7)
unnamed: U12.3, U12.5
unnamed: U12.9, U12.10, U12.11

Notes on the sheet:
1+2: 4 MiB Game Support 2+3: Original Factory Config

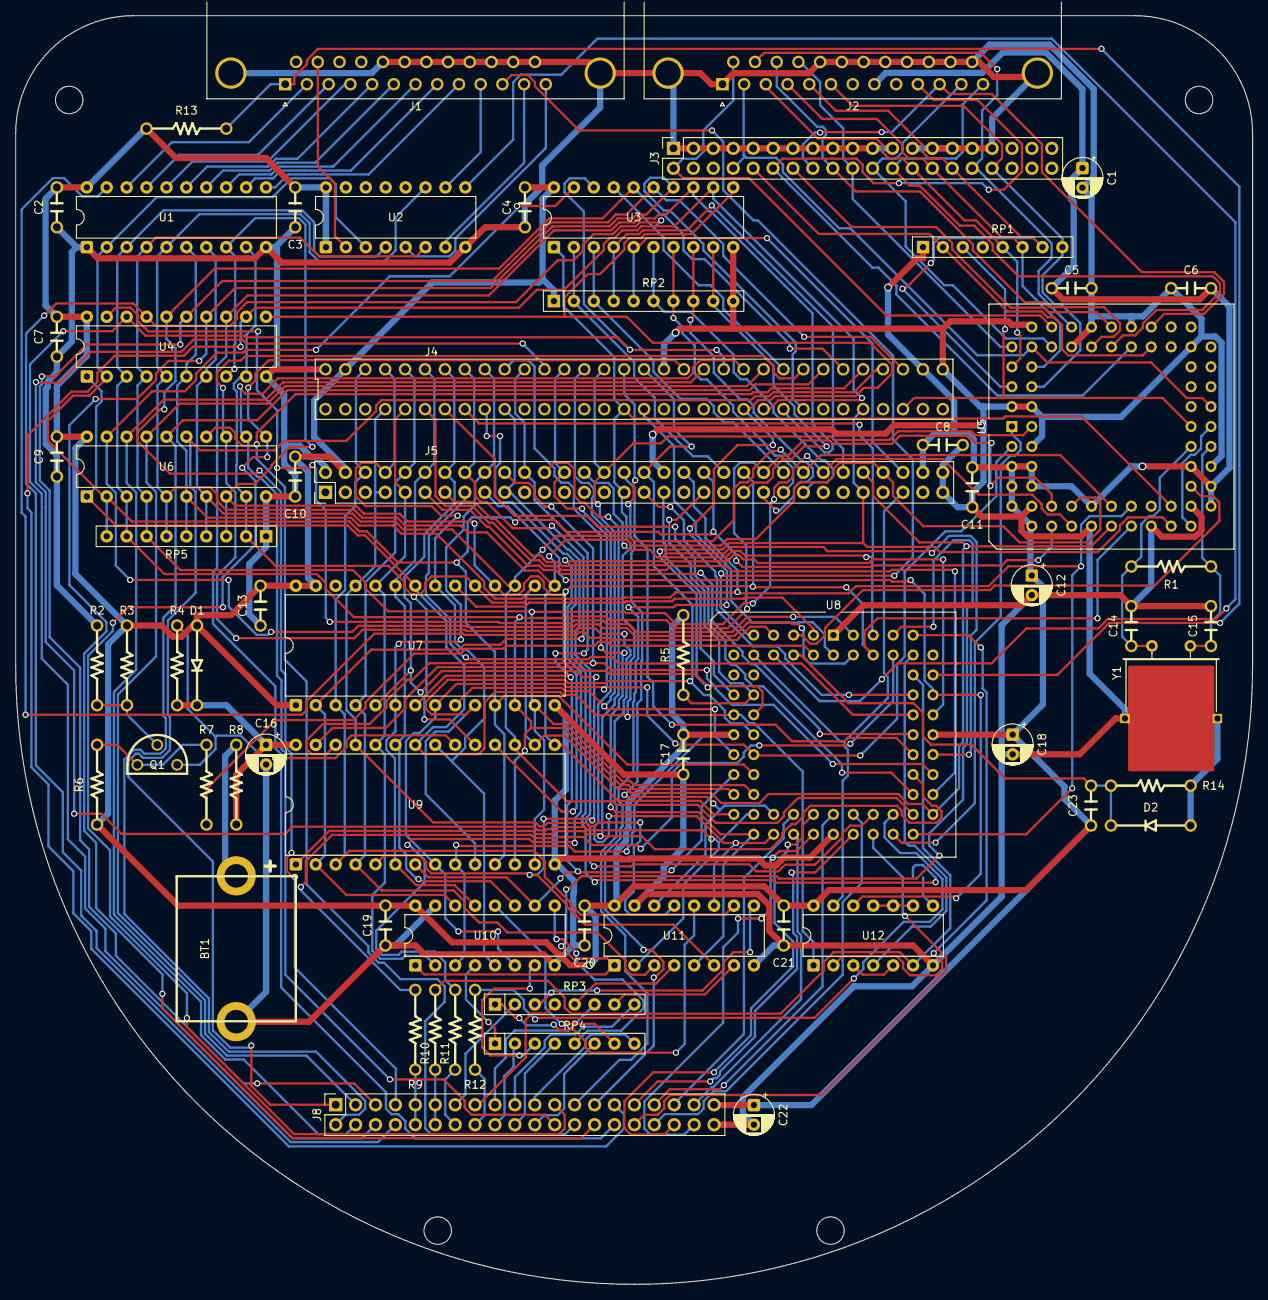
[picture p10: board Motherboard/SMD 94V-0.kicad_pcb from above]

Board: 2 copper layers, 157.8 x 161.8 mm, 66 parts (1 on the bottom side), 155 nets.

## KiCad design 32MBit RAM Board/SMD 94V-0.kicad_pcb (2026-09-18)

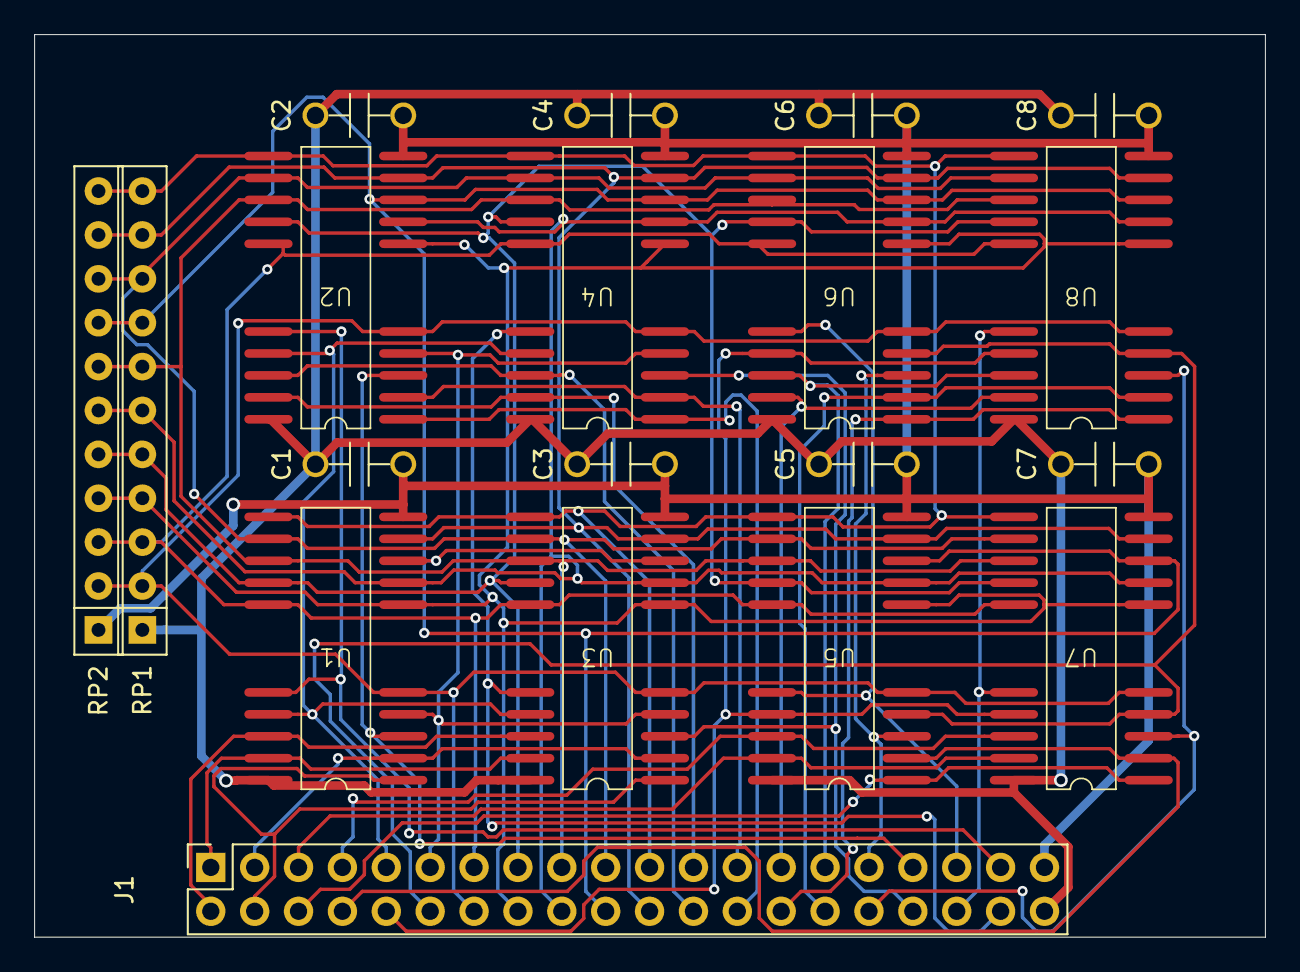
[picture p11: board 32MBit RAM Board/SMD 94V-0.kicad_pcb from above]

Board: 2 copper layers, 71.3 x 52.2 mm, 19 parts (0 on the bottom side), 40 nets.

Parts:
C1, C2, C3, C4, C5, C6, C7, C8: 100 nF; Capacitor
J1: Conn_02x20_Odd_Even; PinHeader_2x20_P2.54mm_Vertical
RP1, RP2: R_Network10; R_Array_SIP11
U1, U2, U3, U4, U5, U6, U7, U8: KM44C1000ALJ-7

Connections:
/A0: J1.16, RP1.4 (R3), RP2.4 (R3), U1.6 (A0), U2.6 (A0), U3.6 (A0), U4.6 (A0), U5.6 (A0), U6.6 (A0), U7.6 (A0), U8.6 (A0)
/A1: J1.18, RP1.6 (R5), RP2.6 (R5), U1.7 (A1), U2.7 (A1), U3.7 (A1), U4.7 (A1), U5.7 (A1), U6.7 (A1), U7.7 (A1), U8.7 (A1)
/A2: J1.20, RP1.8 (R7), RP2.8 (R7), U1.8 (A2), U2.8 (A2), U3.8 (A2), U4.8 (A2), U5.8 (A2), U6.8 (A2), U7.8 (A2), U8.8 (A2)
/A3: J1.22, RP1.10 (R9), RP2.10 (R9), U1.9 (A3), U2.9 (A3), U3.9 (A3), U4.9 (A3), U5.9 (A3), U6.9 (A3), U7.9 (A3), U8.9 (A3)
/A4: J1.21, RP1.11 (R10), RP2.11 (R10), U1.11 (A4), U2.11 (A4), U3.11 (A4), U4.11 (A4), U5.11 (A4), U6.11 (A4), U7.11 (A4), U8.11 (A4)
/A5: J1.19, RP1.9 (R8), RP2.9 (R8), U1.12 (A5), U2.12 (A5), U3.12 (A5), U4.12 (A5), U5.12 (A5), U6.12 (A5), U7.12 (A5), U8.12 (A5)
/A6: J1.17, RP1.7 (R6), RP2.7 (R6), U1.13 (A6), U2.13 (A6), U3.13 (A6), U4.13 (A6), U5.13 (A6), U6.13 (A6), U7.13 (A6), U8.13 (A6)
/A7: J1.15, RP1.5 (R4), RP2.5 (R4), U1.14 (A7), U2.14 (A7), U3.14 (A7), U4.14 (A7), U5.14 (A7), U6.14 (A7), U7.14 (A7), U8.14 (A7)
/A8: J1.13, RP1.3 (R2), RP2.3 (R2), U1.15 (A8), U2.15 (A8), U3.15 (A8), U4.15 (A8), U5.15 (A8), U6.15 (A8), U7.15 (A8), U8.15 (A8)
/A9: J1.14, RP1.2 (R1), RP2.2 (R1), U1.5 (A9), U2.5 (A9), U3.5 (A9), U4.5 (A9), U5.5 (A9), U6.5 (A9), U7.5 (A9), U8.5 (A9)
/GND: C1.1, C2.1, C3.1, C4.1, C5.1, C6.1, C7.1, C8.1, J1.40, RP1.1 (common), U1.20 (GND), U2.20 (GND), U3.20 (GND), U4.20 (GND), U5.20 (GND), U6.20 (GND), U7.20 (GND), U8.20 (GND)
/U1-4.~CAS: J1.9, U1.17 (~CAS), U2.17 (~CAS), U3.17 (~CAS), U4.17 (~CAS)
/U1-4.~RAS: J1.11, U1.4 (~RAS), U2.4 (~RAS), U3.4 (~RAS), U4.4 (~RAS)
/U1-U2.~OE: J1.37, U1.16 (~OE), U2.16 (~OE)
/U1-U2.~W: J1.33, U1.3 (~W), U2.3 (~W)
/U1-U3.DQ0: J1.4, U1.1 (DQ0), U3.1 (DQ0)
/U1-U3.DQ1: J1.3, U1.2 (DQ1), U3.2 (DQ1)
/U1-U3.DQ2: J1.2, U1.18 (DQ2), U3.18 (DQ2)
/U1-U3.DQ3: J1.1, U1.19 (DQ3), U3.19 (DQ3)
/U2-U4.DQ0: J1.26, U2.1 (DQ0), U4.1 (DQ0)
/U2-U4.DQ1: J1.25, U2.2 (DQ1), U4.2 (DQ1)
/U2-U4.DQ2: J1.24, U2.18 (DQ2), U4.18 (DQ2)
/U2-U4.DQ3: J1.23, U2.19 (DQ3), U4.19 (DQ3)
/U3-U4.~OE: J1.38, U3.16 (~OE), U4.16 (~OE)
/U3-U4.~W: J1.34, U3.3 (~W), U4.3 (~W)
/U5-8.~CAS: J1.10, U5.17 (~CAS), U6.17 (~CAS), U7.17 (~CAS), U8.17 (~CAS)
/U5-8.~RAS: J1.12, U5.4 (~RAS), U6.4 (~RAS), U7.4 (~RAS), U8.4 (~RAS)
/U5-U6.~OE: J1.35, U5.16 (~OE), U6.16 (~OE)
/U5-U6.~W: J1.31, U5.3 (~W), U6.3 (~W)
/U5-U7.DQ0: J1.6, U5.1 (DQ0), U7.1 (DQ0)
/U5-U7.DQ1: J1.8, U5.2 (DQ1), U7.2 (DQ1)
/U5-U7.DQ2: J1.7, U5.18 (DQ2), U7.18 (DQ2)
/U5-U7.DQ3: J1.5, U5.19 (DQ3), U7.19 (DQ3)
/U6-U8.DQ0: J1.28, U6.1 (DQ0), U8.1 (DQ0)
/U6-U8.DQ1: J1.30, U6.2 (DQ1), U8.2 (DQ1)
/U6-U8.DQ2: J1.29, U6.18 (DQ2), U8.18 (DQ2)
/U6-U8.DQ3: J1.27, U6.19 (DQ3), U8.19 (DQ3)
/U7-U8.~OE: J1.36, U7.16 (~OE), U8.16 (~OE)
/U7-U8.~W: J1.32, U7.3 (~W), U8.3 (~W)
/VCC: C1.2, C2.2, C3.2, C4.2, C5.2, C6.2, C7.2, C8.2, J1.39, RP2.1 (common), U1.10 (VCC), U2.10 (VCC), U3.10 (VCC), U4.10 (VCC), U5.10 (VCC), U6.10 (VCC), U7.10 (VCC), U8.10 (VCC)

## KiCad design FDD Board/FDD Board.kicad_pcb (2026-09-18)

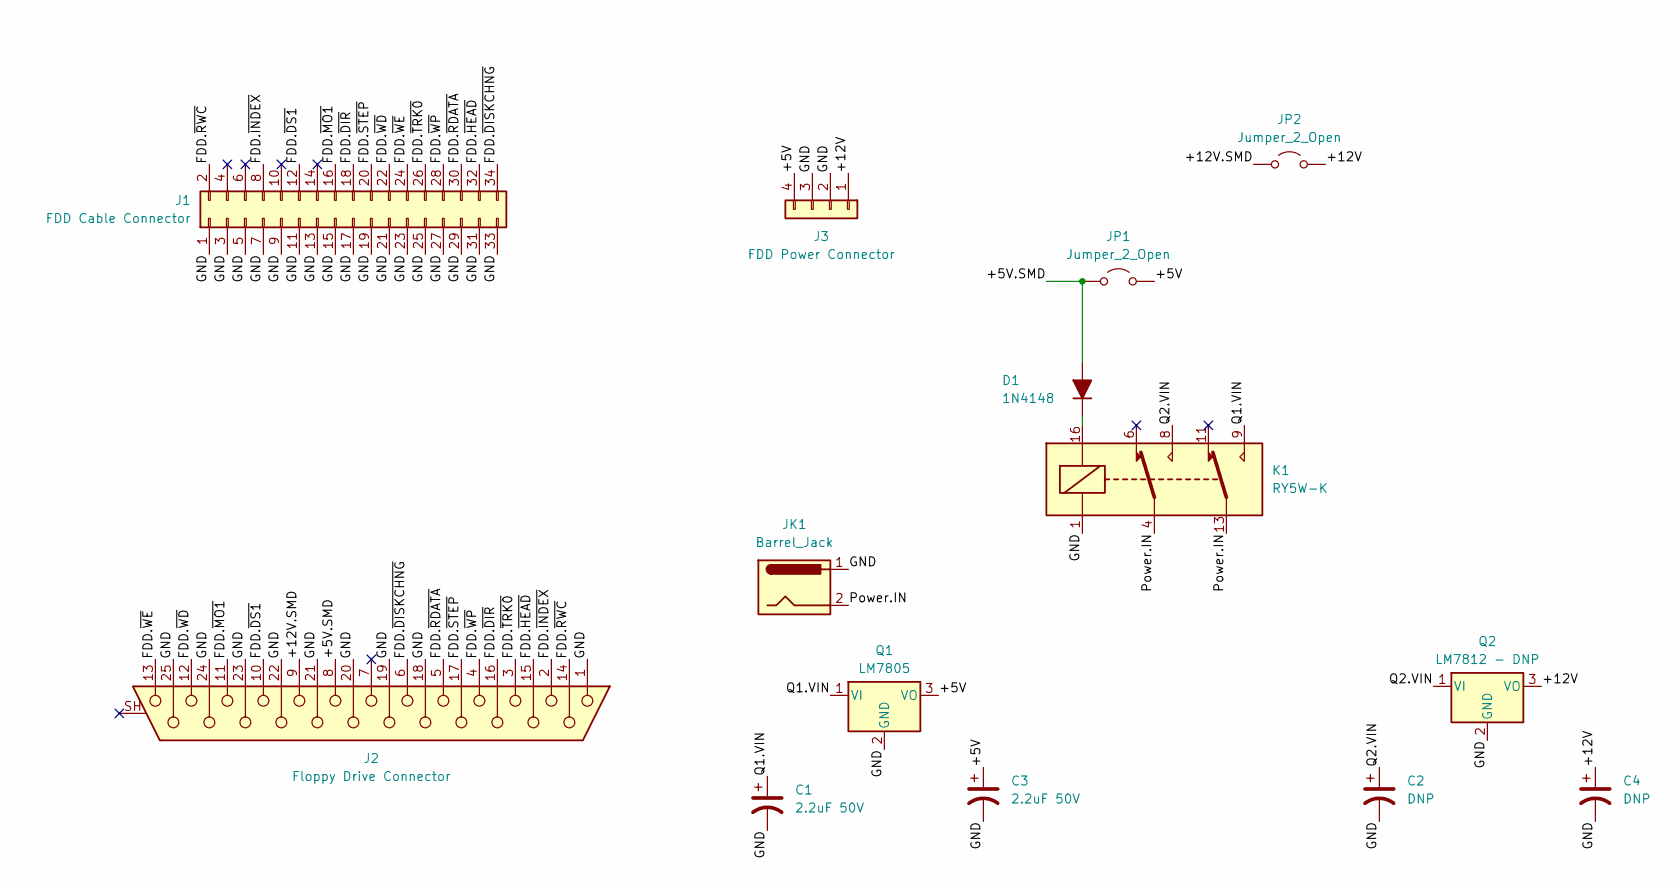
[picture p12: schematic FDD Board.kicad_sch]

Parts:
C1: 2.2uF 50V; CP_Radial_D6.3mm_P2.50mm
C2: DNP; CP_Radial_D6.3mm_P2.50mm
C3: 2.2uF 50V; CP_Radial_D10.0mm_P5.00mm
C4: DNP; CP_Radial_D10.0mm_P5.00mm
D1: 1N4148; Diode
J1: FDD Cable Connector; PinHeader_2x17_P2.54mm_Vertical
J2: Floppy Drive Connector; DSUB-25_Socket_Horizontal_P2.77x2.84mm_EdgePinOffset7.70mm_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
J3: FDD Power Connector; FDD Power
JK1: Barrel_Jack; BarrelJack_Horizontal
JP1, JP2: Jumper_2_Open; PinHeader_1x02_P2.54mm_Vertical
K1: RY5W-K; Relay_DPDT_Omron_G5V-2
Q1: LM7805; TO-220-3_Vertical
Q2: LM7812 - DNP; TO-220-3_Vertical

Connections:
/+5V: C3.1, J3.4, JP1.2 (B), Q1.3 (VO)
/+5V.SMD: D1.2 (A), J2.8, JP1.1 (A)
/+12V: C4.1, J3.1, JP2.2 (B), Q2.3 (VO)
/+12V.SMD: J2.9, JP2.1 (A)
/FDD.~DIR: J1.18, J2.16
/FDD.~DISKCHNG: J1.34, J2.6
/FDD.~DS1: J1.12, J2.10
/FDD.~HEAD: J1.32, J2.15
/FDD.~INDEX: J1.8, J2.2
/FDD.~MO1: J1.16, J2.11
/FDD.~RDATA: J1.30, J2.5
/FDD.~RWC: J1.2, J2.14
/FDD.~STEP: J1.20, J2.17
/FDD.~TRK0: J1.26, J2.3
/FDD.~WD: J1.22, J2.12
/FDD.~WE: J1.24, J2.13
/FDD.~WP: J1.28, J2.4
/GND: C1.2, C2.2, C3.2, C4.2, J1.1, J1.3, J1.5, J1.7, J1.9, J1.11, J1.13, J1.15, J1.17, J1.19, J1.21, J1.23, J1.25, J1.27, J1.29, J1.31, J1.33, J2.1, J2.18, J2.19, J2.20, J2.21, J2.22, J2.23, J2.24, J2.25, J3.2, J3.3, JK1.1, K1.1, Q1.2 (GND), Q2.2 (GND)
/Power.IN: JK1.2, K1.4, K1.13
/Q1.VIN: C1.1, K1.9, Q1.1 (VI)
/Q2.VIN: C2.1, K1.8, Q2.1 (VI)
unnamed: D1.1 (K), K1.16

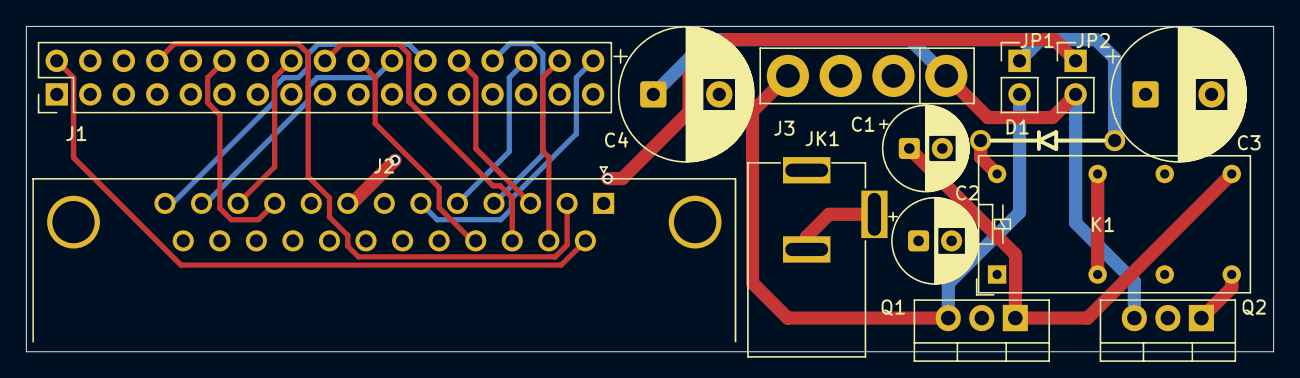
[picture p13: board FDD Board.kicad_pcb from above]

Board: 4 copper layers, 94.5 x 24.7 mm, 14 parts (0 on the bottom side), 22 nets.
